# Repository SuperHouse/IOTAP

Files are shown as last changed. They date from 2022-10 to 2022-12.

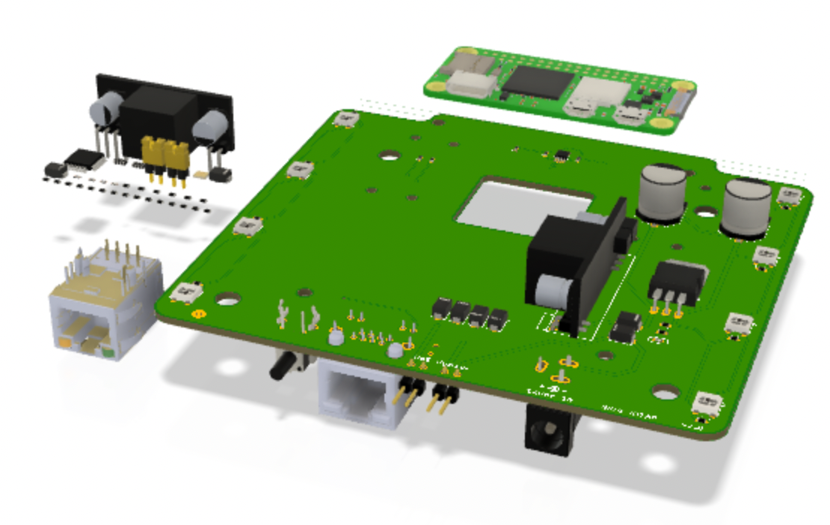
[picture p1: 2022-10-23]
Images/Screen Shot 2022-05-21 at 9.01.56 pm.png

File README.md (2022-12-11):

IoT WiFi Access Point
=====================

Simple WiFi devices typically don't support enterprise level WiFi
authentication, which means they all share a single password. If
an IoT device is compromised, the password can be exposed and changing
the password on many devices is painful.

This project aims to create a WiFi access point that supports
personal pre-shared keys (PPSK) so that each device can be given its
own password. Access privileges for any device can then be revoked
without requiring changes to any other device.

More information is available at:

  https://www.superhouse.tv/iotap

Hardware
--------
The "Hardware" directory contains the PCB design as an EAGLE project.

Enclosure
---------
The enclosure is model AK-NW-40 from SZOMK:

  https://www.aliexpress.com/item/33043522751.html

Credits
-------
 * Jonathan Oxer <jon@oxer.com.au>
 * Tony Smith
 * Austin's Creations <https://www.austinscreations.ca/>
 * All the folks watching and commenting on the streams!

License
-------
Copyright 2020-2022 SuperHouse Automation Pty Ltd  www.superhouse.tv  

The hardware portion of this project is licensed under the TAPR Open
Hardware License (www.tapr.org/OHL). The "license" folder within this
repository contains a copy of this license in plain text format.

The software portion of this project is licensed under the Simplified
BSD License. The "licence" folder within this project contains a
copy of this license in plain text format.

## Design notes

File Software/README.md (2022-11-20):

## Software setup for IoT-AP

 * Download Raspberry Pi Imager.
 * Insert an SD card into your computer.
 * For operating system, select "Raspberry Pi OS (other) -> Raspberry Pi OS Lite (32-bit)"
 * Select your SD card as the destination.
 * Click the cog icon to open the config options menu.
 * Set a suitable hostname, such as "iotap-1.local".
 * Enable SSH, with either a password or a public key.
 * Set a username and password.
 * Configure wireless LAN as a client of your existing network. This is needed for setup!
 * Set the Wireless LAN country option.
 * Save.
 * Write.
 * When finished, eject the card and put it in your IoT-AP.
 * Power it up.
 * After a couple of minutes, SSH to it: "ssh iotap-1.local" or similar.
 * Copy this whole folder to it from your local computer: "scp -r Software pi@iotap-1.local:" or similar.
 * On the AP, go into the copied directory: "cd Software".
 * Run the setup script: "sudo ./setup.sh".
 * Reboot the AP: "sudo reboot".
 * After a few minutes the LEDs will start blinking and the AP will be online.

HOWEVER, there is a bug: the bridge doesn't have the interfaces added properly.
This has to be run manually:
  sudo brctl addif br0 eth0

## Usage

 * To check connected clients: " sta_all"
 * To add a client, edit "/etc/hostapd/hostapd.wpa_psk"
 * Then "sudo systemctl restart hostapd"
 * To check bridge status: "brctl show"

Not working:
pi@iotap-2:~ $ brctl show
bridge name	bridge id		STP enabled	interfaces
br0		8000.e45f01758d5e	no		wlan0

Working:
pi@iotap-1:~ $ brctl show
bridge name	bridge id		STP enabled	interfaces
br0		8000.b827eb19ea24	no		eth0
							wlan0

sudo hostapd_cli sta_all
sudo hostapd_cli list_sta
cat /etc/default/hostapd
sudo echo "DAEMON_CONF=\"/etc/hostapd/hostapd.conf\"" >> /etc/default/hostapd

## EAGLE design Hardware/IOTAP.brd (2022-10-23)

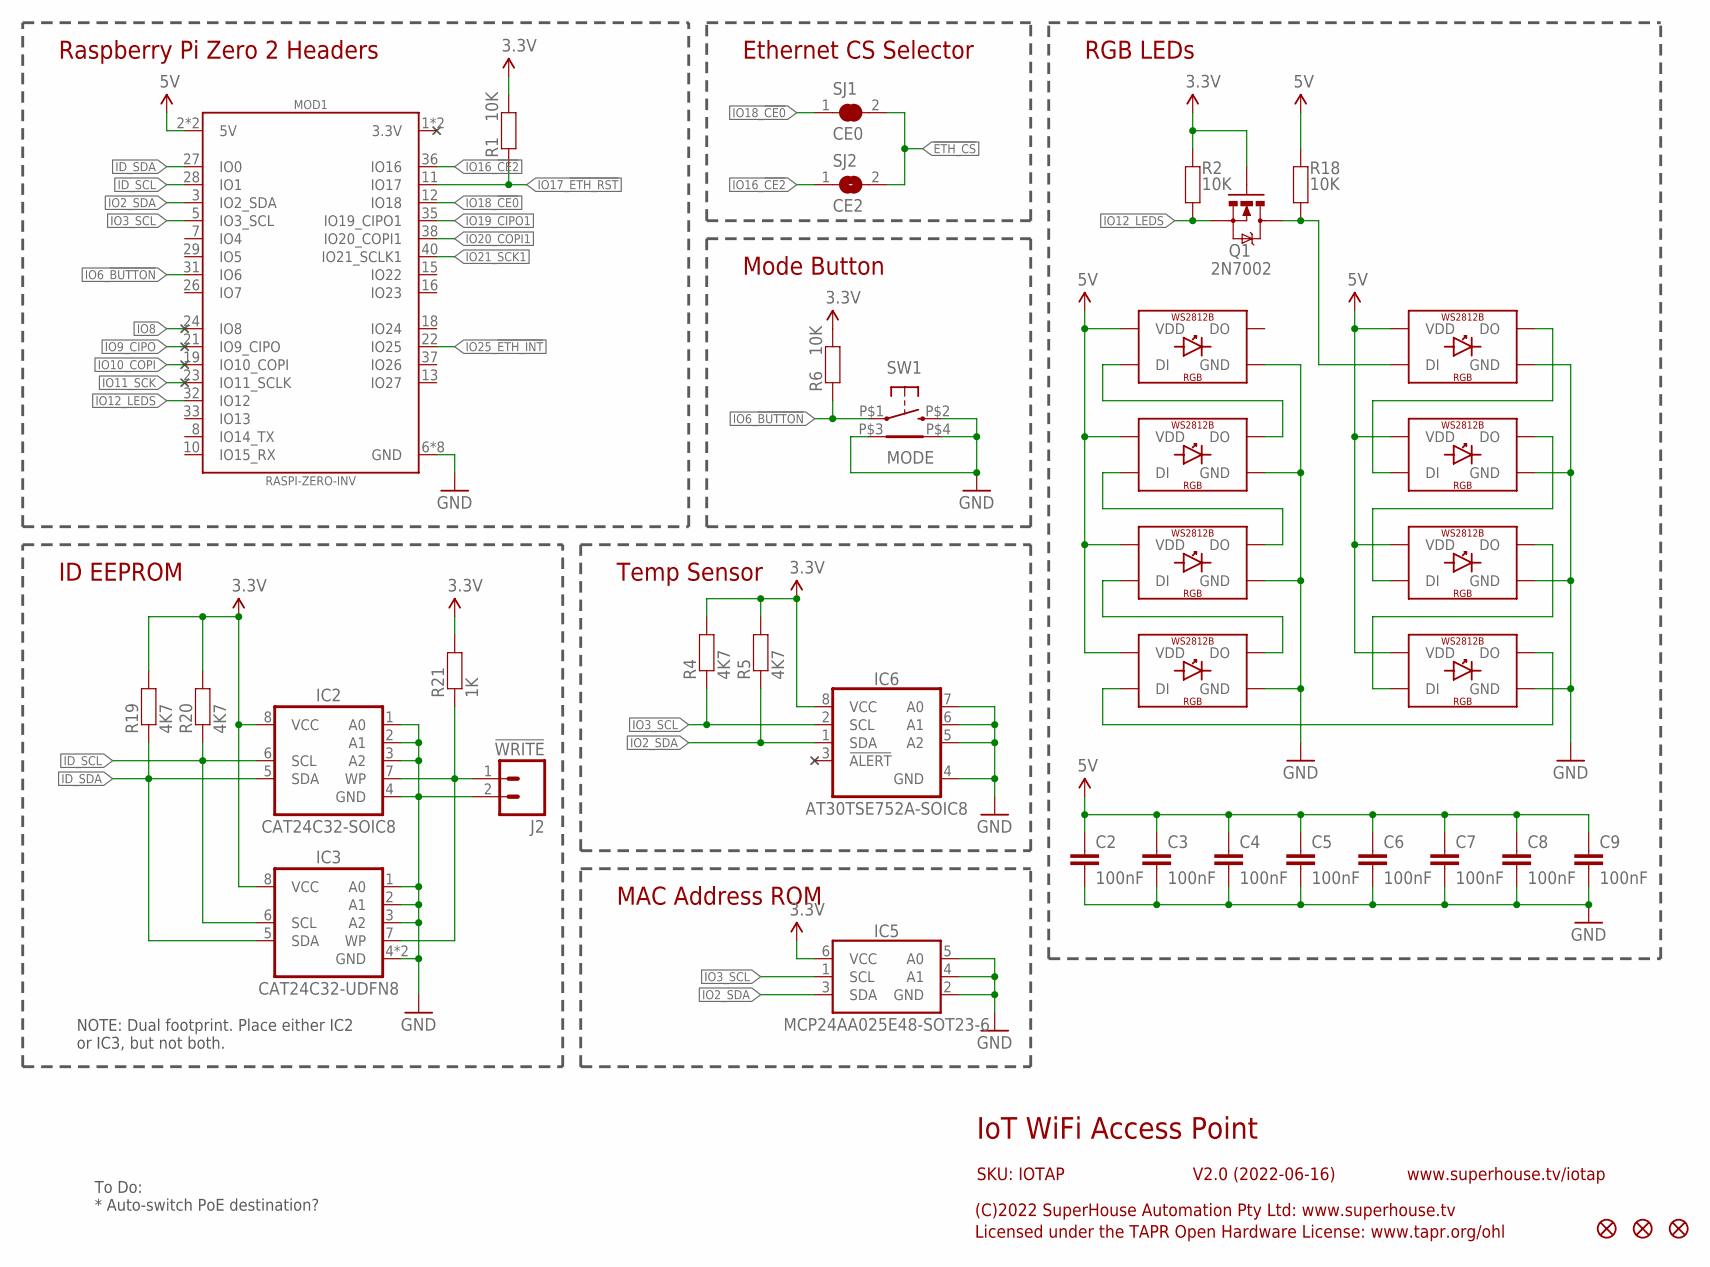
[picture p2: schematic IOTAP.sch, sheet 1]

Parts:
C2, C3, C4, C5, C6, C7, C8, C9: 100nF; C0603
FID1, FID2, FID3: FIDUCIAL1X2.5; FIDUCIAL-1X2.5
IC2: CAT24C32-SOIC8; SOIC8
IC3: CAT24C32-UDFN8; UDFN8
IC5: MCP24AA025E48-SOT23-6; SOT23-6
IC6: AT30TSE752A-SOIC8; SOIC8
J2: !WRITE; 1X02
LED1, LED2, LED3, LED4, LED5, LED6, LED7, LED8: WS2812B5050; WS2812B
MOD1: RASPI-ZERO-INV; RPI-ZERO-INV
Q1: 2N7002; SOT23-3
R1, R2, R6, R18: 10K; R0603
R4, R5, R19, R20: 4K7; R0603
R21: 1K; R0603
SJ1: CE0; SJC
SJ2: CE2; SJ
SW1: MODE; TC-120V

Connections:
3.3V: IC2.8 (VCC), IC3.8 (VCC), IC5.6 (VCC), IC6.8 (VCC), Q1.1 (G), R1.2, R2.2, R4.2, R5.2, R6.2, R19.2, R20.2, R21.2; also elsewhere on the board
5V: C2.1, C3.1, C4.1, C5.1, C6.1, C7.1, C8.1, C9.1, LED1.1-VDD (VDD), LED2.1-VDD (VDD), LED3.1-VDD (VDD), LED4.1-VDD (VDD), LED5.1-VDD (VDD), LED6.1-VDD (VDD), LED7.1-VDD (VDD), LED8.1-VDD (VDD), MOD1.2 (5V), MOD1.4 (5V), R18.2; also elsewhere on the board
!ETH_CS: SJ1.2, SJ2.2; also elsewhere on the board
GND: C2.2, C3.2, C4.2, C5.2, C6.2, C7.2, C8.2, C9.2, IC2.1 (A0), IC2.2 (A1), IC2.3 (A2), IC2.4 (GND), IC3.1 (A0), IC3.2 (A1), IC3.3 (A2), IC3.4 (GND), IC3.PAD (GND), IC5.2 (GND), IC5.4 (A1), IC5.5 (A0), IC6.4 (GND), IC6.5 (A2), IC6.6 (A1), IC6.7 (A0), J2.2, LED1.3-GND (GND), LED2.3-GND (GND), LED3.3-GND (GND), LED4.3-GND (GND), LED5.3-GND (GND), LED6.3-GND (GND), LED7.3-GND (GND), LED8.3-GND (GND), MOD1.6 (GND), MOD1.9 (GND), MOD1.14 (GND), MOD1.20 (GND), MOD1.25 (GND), MOD1.30 (GND), MOD1.34 (GND), MOD1.39 (GND), SW1.P$2 (2), SW1.P$3 (TAB1), SW1.P$4 (TAB2); also elsewhere on the board
ID_SCL: IC2.6 (SCL), IC3.6 (SCL), MOD1.28 (IO1), R20.1
ID_SDA: IC2.5 (SDA), IC3.5 (SDA), MOD1.27 (IO0), R19.1
IO2_SDA: IC5.3 (SDA), IC6.1 (SDA), MOD1.3 (IO2_SDA), R5.1; also elsewhere on the board
IO3_SCL: IC5.1 (SCL), IC6.2 (SCL), MOD1.5 (IO3_SCL), R4.1; also elsewhere on the board
IO6_!BUTTON: MOD1.31 (IO6), R6.1, SW1.P$1 (1)
IO8: MOD1.24 (IO8)
IO9_CIPO: MOD1.21 (IO9_CIPO)
IO10_COPI: MOD1.19 (IO10_COPI)
IO11_SCK: MOD1.23 (IO11_SCLK)
IO12_LEDS: MOD1.32 (IO12), Q1.2 (S), R2.1
IO16_!CE2: MOD1.36 (IO16), SJ2.1
IO17_!ETH_RST: MOD1.11 (IO17), R1.1; also elsewhere on the board
IO18_!CE0: MOD1.12 (IO18), SJ1.1
IO19_CIPO1: MOD1.35 (IO19_CIPO1); also elsewhere on the board
IO20_COPI1: MOD1.38 (IO20_COPI1); also elsewhere on the board
IO21_SCK1: MOD1.40 (IO21_SCLK1); also elsewhere on the board
IO25_!ETH_INT: MOD1.22 (IO25); also elsewhere on the board
LEDS: LED1.4-DIN (DI), Q1.3 (D), R18.1
unnamed: IC2.7 (WP), IC3.7 (WP), J2.1, R21.1
unnamed: LED4.2-DOUT (DO), LED5.4-DIN (DI)
unnamed: LED5.2-DOUT (DO), LED6.4-DIN (DI)
unnamed: LED6.2-DOUT (DO), LED7.4-DIN (DI)
unnamed: LED7.2-DOUT (DO), LED8.4-DIN (DI)
unnamed: LED1.2-DOUT (DO), LED2.4-DIN (DI)
unnamed: LED2.2-DOUT (DO), LED3.4-DIN (DI)
unnamed: LED3.2-DOUT (DO), LED4.4-DIN (DI)

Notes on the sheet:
IoT WiFi Access Point
V2.0 (2022-06-16)
SKU: IOTAP
(C)2022 SuperHouse Automation Pty Ltd: www.superhouse.tv
Licensed under the TAPR Open Hardware License: www.tapr.org/ohl
www.superhouse.tv/iotap
RGB LEDs
Raspberry Pi Zero 2 Headers
To Do: * Auto-switch PoE destination?
Mode Button
Temp Sensor
Ethernet CS Selector
ID EEPROM
NOTE: Dual footprint. Place either IC2 or IC3, but not both.
MAC Address ROM

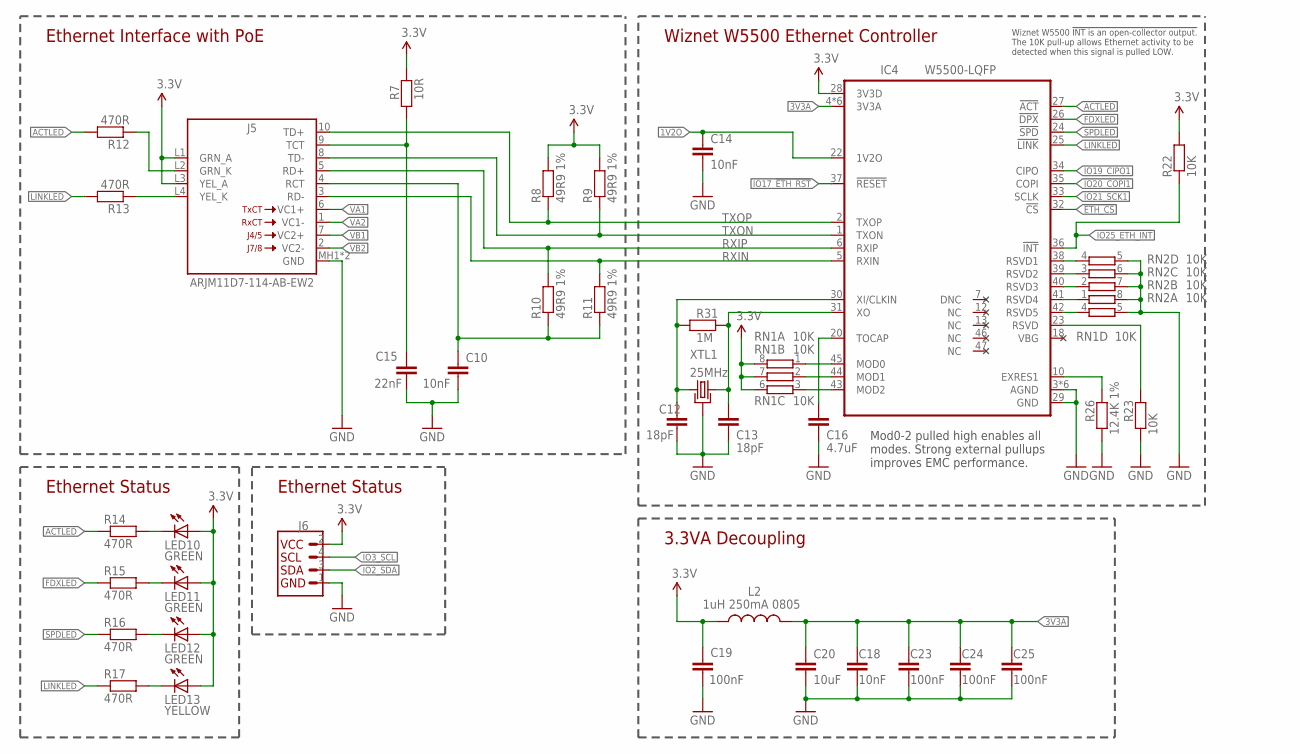
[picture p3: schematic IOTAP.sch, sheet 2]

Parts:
C10, C14, C18: 10nF; C0603
C12, C13: 18pF; C0603
C15: 22nF; C0603
C16: 4.7uF; C0603
C19, C23, C24, C25: 100nF; C0603
C20: 10uF; C0805
IC4: W5500-LQFP; LQFP48
J5: ARJM11D7-114-AB-EW2; ARJM11D7114ABEW2
J6: QWIICJS-1MM; 1X04_QWIIC_1MM_RA
L2: 1uH 250mA 0805; L2012C
LED10, LED11, LED12: GREEN; LED-0603
LED13: YELLOW; LED-0603
R7: 10R; R0603
R8, R9, R10, R11: 49R9 1%; R0603
R12, R13, R14, R15, R16, R17: 470R; R0603
R22, R23: 10K; R0603
R26: 12.4K 1%; R0603
R31: 1M; R0603
RN1, RN2: 10K; CAY16
XTL1: 25MHz; CRYSTAL-SMD-3X2

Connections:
1V2O: C14.1, IC4.22 (1V2O)
3.3V: C19.1, IC4.28 (3V3D), J5.L1 (GRN_A), J5.L3 (YEL_A), J6.2, L2.1, LED10.A, LED11.A, LED12.A, LED13.A, R7.1, R8.2, R9.2, R22.2, RN1.6 (2), RN1.7 (2), RN1.8 (2); also elsewhere on the board
3V3A: C18.1, C20.1, C23.1, C24.1, C25.1, IC4.4 (3V3A), IC4.8 (3V3A), IC4.11 (3V3A), IC4.15 (3V3A), IC4.17 (3V3A), IC4.21 (3V3A), L2.2
!ETH_CS: IC4.32 (!CS); also elsewhere on the board
ACTLED: IC4.27 (!ACT), R12.2, R14.1
FDXLED: IC4.26 (!DPX), R15.1
GND: C10.2, C12.2, C13.2, C14.2, C15.2, C16.2, C18.2, C19.2, C20.2, C23.2, C24.2, C25.2, IC4.3 (AGND), IC4.9 (AGND), IC4.14 (AGND), IC4.16 (AGND), IC4.19 (AGND), IC4.29 (GND), IC4.48 (AGND), J5.MH1 (GND), J5.MH2 (GND), J6.1, R23.2, R26.2, RN1.5 (2), RN2.5 (2), RN2.6 (2), RN2.7 (2), RN2.8 (2), XTL1.2 (GND), XTL1.4 (GND); also elsewhere on the board
IO2_SDA: J6.3; also elsewhere on the board
IO3_SCL: J6.4; also elsewhere on the board
IO17_!ETH_RST: IC4.37 (!RESET); also elsewhere on the board
IO19_CIPO1: IC4.34 (CIPO); also elsewhere on the board
IO20_COPI1: IC4.35 (COPI); also elsewhere on the board
IO21_SCK1: IC4.33 (SCLK); also elsewhere on the board
IO25_!ETH_INT: IC4.36 (!INT), R22.1; also elsewhere on the board
LINKLED: IC4.25 (!LINK), R13.2, R17.1
unnamed: J5.L4 (YEL_K), R13.1
unnamed: J5.L2 (GRN_K), R12.1
unnamed: C13.1, IC4.31 (XO), R31.1, XTL1.3 (2)
unnamed: C10.1, J5.4 (RCT), R10.1, R11.1
unnamed: LED12.C, R16.2
unnamed: C12.1, IC4.30 (XI/CLKIN), R31.2, XTL1.1
unnamed: LED13.C, R17.2
unnamed: C16.1, IC4.20 (TOCAP)
unnamed: C15.1, J5.9 (TCT), R7.2
unnamed: IC4.10 (EXRES1), R26.1
unnamed: IC4.23 (RSVD), R23.1
unnamed: IC4.45 (MOD0), RN1.1
unnamed: IC4.44 (MOD1), RN1.2 (1)
unnamed: IC4.43 (MOD2), RN1.3 (1)
unnamed: IC4.42 (RSVD5), RN1.4 (1)
unnamed: IC4.41 (RSVD4), RN2.1
unnamed: IC4.40 (RSVD3), RN2.2 (1)
unnamed: IC4.39 (RSVD2), RN2.3 (1)
unnamed: IC4.38 (RSVD1), RN2.4 (1)
unnamed: LED11.C, R15.2
unnamed: LED10.C, R14.2
RXIN: IC4.5 (RXIN), J5.3 (RD-), R11.2
RXIP: IC4.6 (RXIP), J5.5 (RD+), R10.2
SPDLED: IC4.24 (!SPD), R16.1
TXON: IC4.1 (TXON), J5.8 (TD-), R9.1
TXOP: IC4.2 (TXOP), J5.10 (TD+), R8.1
VA1: J5.6 (VC1+); also elsewhere on the board
VA2: J5.1 (VC1-); also elsewhere on the board
VB1: J5.7 (VC2+); also elsewhere on the board
VB2: J5.2 (VC2-); also elsewhere on the board

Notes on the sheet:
Ethernet Status
Ethernet Interface with PoE
Wiznet W5500 Ethernet Controller
Mod0-2 pulled high enables all modes. Strong external pullups improves EMC performance.
Wiznet W5500 !INT is an open-collector output. The 10K pull-up allows Ethernet activity to be detected when this signal is pulled LOW.
3.3VA Decoupling

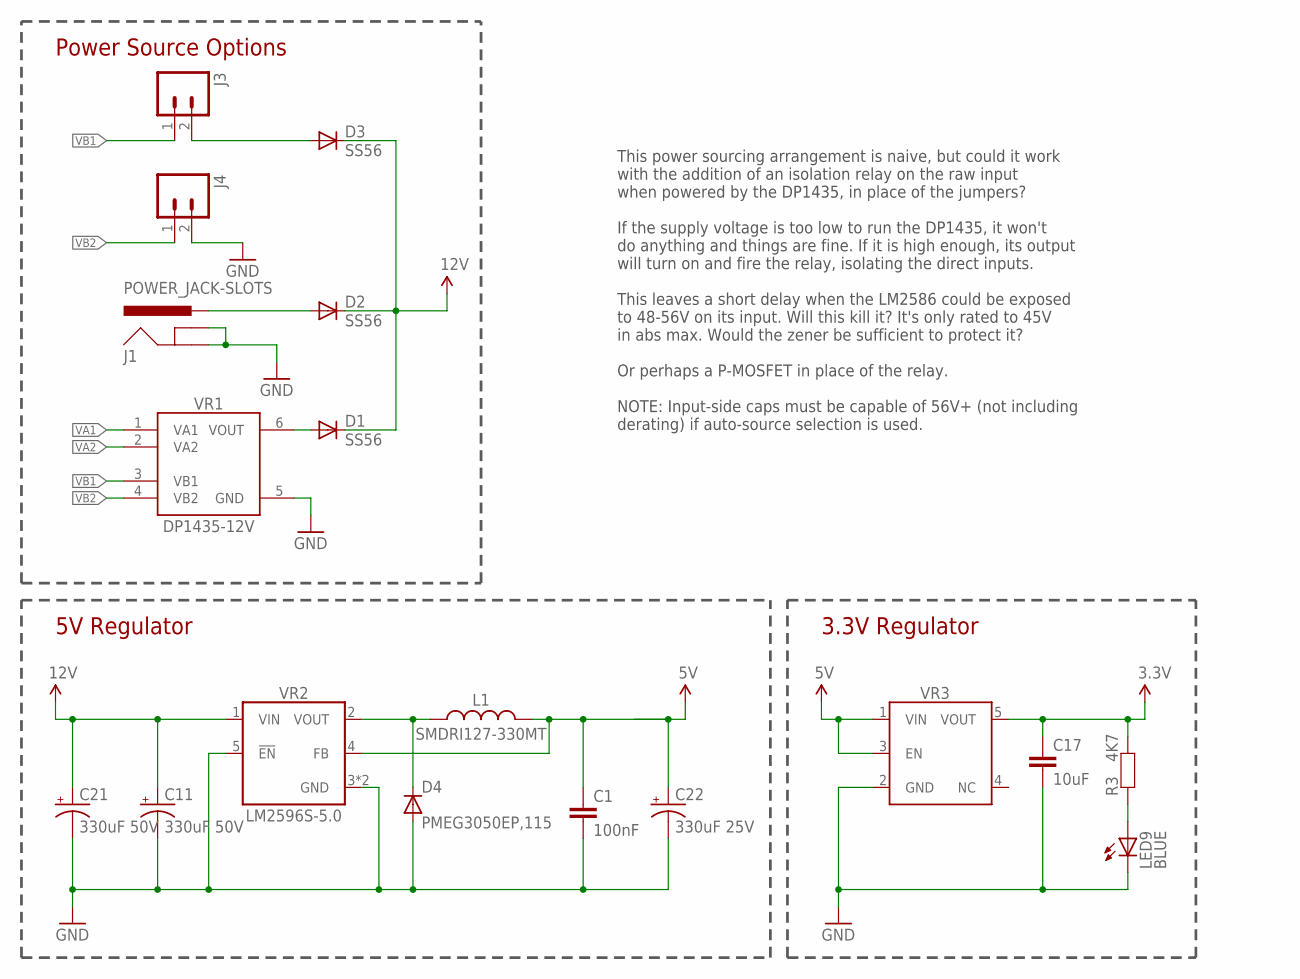
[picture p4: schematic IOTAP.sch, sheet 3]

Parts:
C1: 100nF; C0603
C11, C21: 330uF 50V; PANASONIC_G
C17: 10uF; C0805
C22: 330uF 25V; PANASONIC_G
D1, D2, D3: SS56; SMA-DIODE
D4: PMEG3050EP,115; SOD-128
J1: POWER_JACK-SLOTS; POWER_JACK_SLOTS
J3, J4: M02-PIN-RA; 1X02-P-RA
L1: SMDRI127-330MT; INDPM120120X800N
LED9: BLUE; LED-0603
R3: 4K7; R0603
VR1: DP1435-12V; DP1435
VR2: LM2596S-5.0; TO170P1435X465-6N
VR3: AP2112KSOT25; SOT23-5

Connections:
3.3V: C17.1, R3.2, VR3.5 (VOUT); also elsewhere on the board
5V: C1.1, C22.+, L1.2, VR2.4 (FB), VR3.1 (VIN), VR3.3 (EN); also elsewhere on the board
12V: C11.+, C21.+, D1.C, D2.C, D3.C, VR2.1 (VIN)
GND: C1.2, C11.-, C17.2, C21.-, C22.-, D4.2 (A), J1.GND, J1.GNDBREAK, J4.2, LED9.C, VR1.5 (GND), VR2.3 (GND), VR2.5 (!EN), VR2.6 (GND), VR3.2 (GND); also elsewhere on the board
unnamed: D3.A, J3.2
unnamed: D4.1 (C), L1.1, VR2.2 (VOUT)
unnamed: LED9.A, R3.1
unnamed: D2.A, J1.PWR
unnamed: D1.A, VR1.6 (VOUT)
VA1: VR1.1 (VA1); also elsewhere on the board
VA2: VR1.2 (VA2); also elsewhere on the board
VB1: J3.1, VR1.3 (VB1); also elsewhere on the board
VB2: J4.1, VR1.4 (VB2); also elsewhere on the board

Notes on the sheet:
Power Source Options
This power sourcing arrangement is naive, but could it work with the addition of an isolation relay on the raw input when powered by the DP1435, in place of the jumpers? If the supply voltage is too low to run the DP1435, it won't do anything and things are fine. If it is high enough, its output wi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
5V Regulator
3.3V Regulator

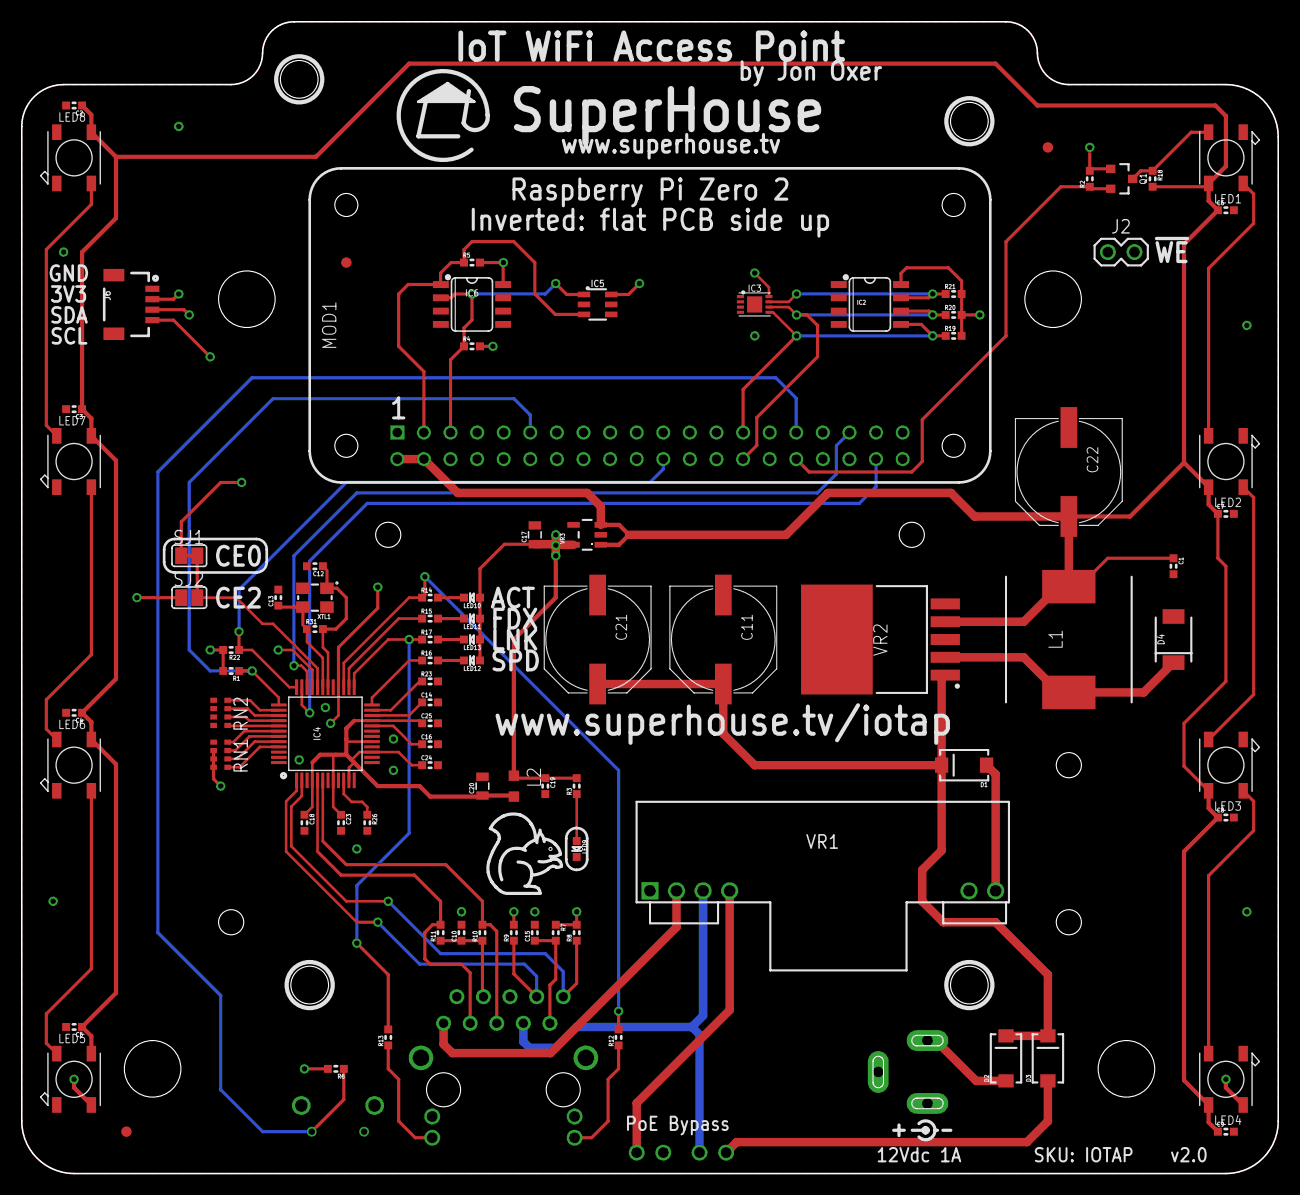
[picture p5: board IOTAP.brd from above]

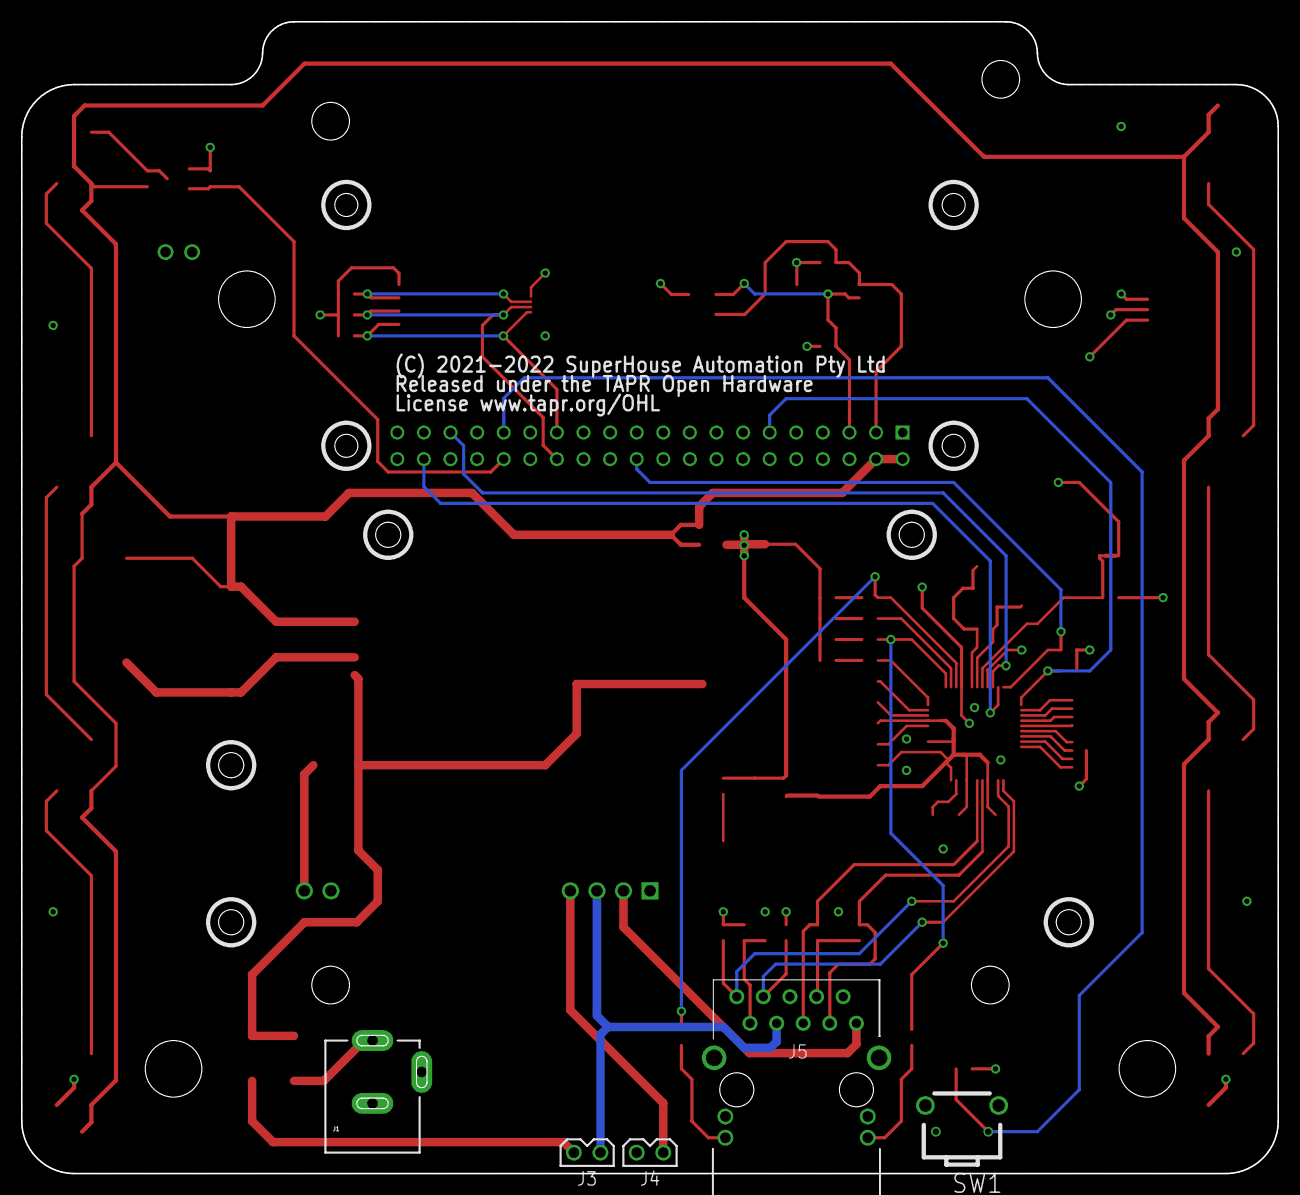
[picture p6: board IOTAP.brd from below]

Board: 4 copper layers, 120.0 x 110.0 mm, 94 parts (5 on the bottom side), 67 nets.

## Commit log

2021-09-28 Initial import.
    [IOTAP.brd, IOTAP.sch]
2021-10-07 Fixed footprint for RJ45 socket.
    [IOTAP.brd, IOTAP.sch]
2022-10-23 Major redesign based on Raspberry Pi Zero 2.
    [IOTAP.brd, IOTAP.sch]
2022-10-23 Added image of board.
2022-10-23 Added link to enclosure.
2022-11-26 Update iotap
    Added 20 second delay before adding interfaces to bridge device
2022-12-11 Added systemctl config to add Eth0 to the bridge device.

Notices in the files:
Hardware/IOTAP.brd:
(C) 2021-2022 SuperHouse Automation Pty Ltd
